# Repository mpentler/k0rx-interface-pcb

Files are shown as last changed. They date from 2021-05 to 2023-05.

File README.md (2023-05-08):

# k0rx-interface-pcb
A PCB implementation of an audio data mode interface designed by K0RX, David Andersen
Photo of PCB

Original circuit here: https://k0rx.com/blog/2017/11/baofeng.html

I made this up into a small 4x4cm PCB to replace a horrible stripboard prototype. I'm releasing the Gerber files and the KiCad project in case anyone wants to have a play. The project has now been upgraded to be compatible with KiCad V6, but some things may need reconnecting. Sorry. Same for V7.

There are more complex interfaces available to make or buy but I loved the simplicity of David's design. A small enclosure could be made for a box, and I've included an example of this in FreeCAD format also.

I had to change some resistors in my implementation as David mentions, and I totally missed out the potentiometer, opting for a single 2k2 resistor (edit 2023: my output is way hot - clearly needs the resistor value increasing). I also added a hard switch for toggling Tx/Rx as well as the optocoupler. I am only using a single audio channel as David does, so you can either leave the other one hanging or send to ground I guess. The Rx resistor may need some adjustment, see what level works for you (breadboard it and test, perhaps). I will change this to potentiometers for a V3 as different radios and PCs can vary wildly in level.

An improvement you may want to add is a proper connector for the radio cable rather than cutting the end off a cable and soldering it directly. Especially if mounting it in a box.

This interface works great for me for SSTV & APRS work and for general audio recording from the radio. The total cost of all of the parts (including PCB fabbing from JLCPCB) is around £15, the most expensive parts being the cables.

# Parts List

* R1 - High value for receive audio, typically 62k-100k Ohm
* R2 - 2.2k Ohm for transmit audio (this may need to be higher also, again, experimentation is useful)
* R3 - 330 Ohm
* C1 - 0.1uF ceramic capacitor
* T1 - 1:1 600 Ohm transformer
* U1 - PC817 Optocoupler to pull PTT to GND
* SW1 - SPDT slide switch for hard TX/RX switching
* J1 - TRRS jack socket
* J2 - Pin header or bare pads - Audio out, GND
* J3 - Pin header or bare pads - Audio in, PTT
* J4 - Pin header or bare pads - RS232

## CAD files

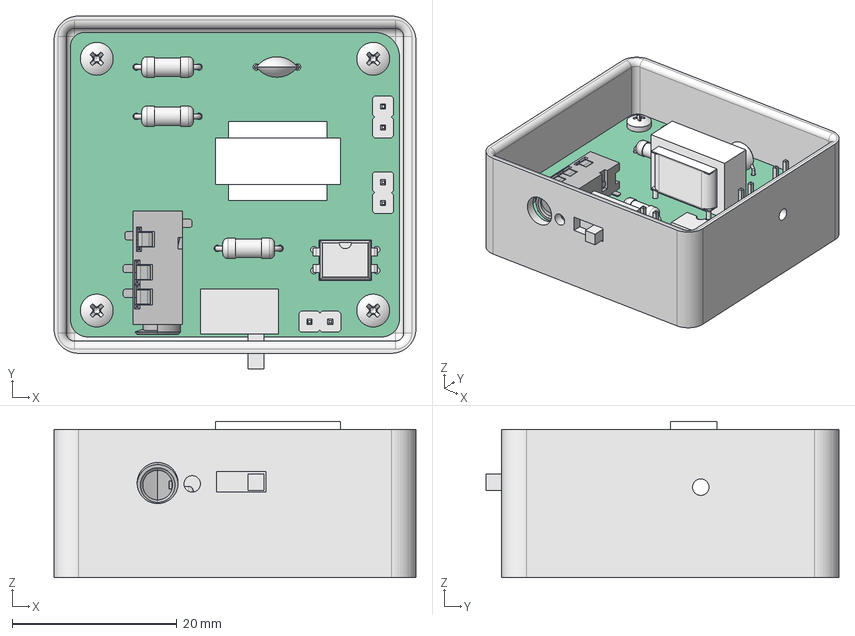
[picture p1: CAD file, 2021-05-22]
FreeCAD Box Design/Data Mode Radio Cable.FCStd
44.0 x 42.9 x 19.0 mm
M2x3-Screw
M2x3-Screw004
M2x3-Screw005
M2x3-Screw006
Pcb_8c7
J1_CUI_DEVICES_SJ2-3574A-SMT-TR_6004B39D
T1_Fusion003_60357E64
R3_R_Axial_DIN0207_L63mm_D25mm_P762mm_Horizontal_5FFD0C60 x 3
C1_C_Disc_D50mm_W25mm_P500mm_5FFD0E08
J2_PinHeader_1x02_P254mm_Vertical_5FFD0CA1 x 3
U1_DIP-4_W7.62mm_5FFD12AE
SW1_Fusion_6035CA9C

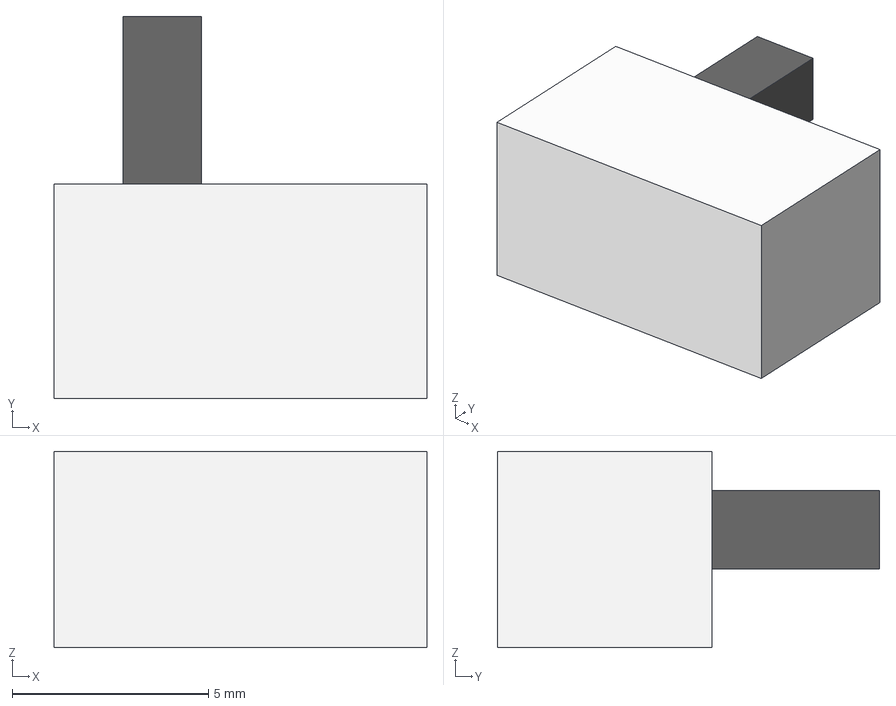
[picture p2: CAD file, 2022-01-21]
KiCad Project/3D Models/SPDT Switch.step
9.50 x 9.73 x 5.00 mm

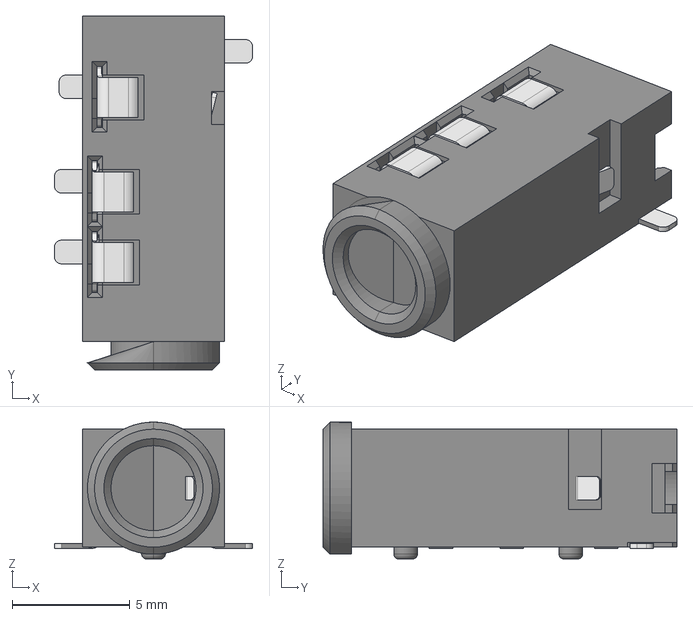
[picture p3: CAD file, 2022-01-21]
KiCad Project/3D Models/PJ-320A.step
8.40 x 15.0 x 5.80 mm

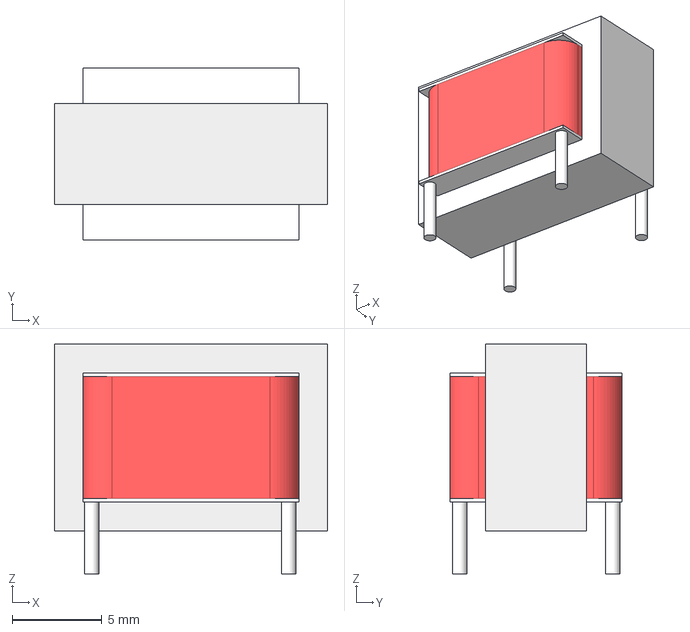
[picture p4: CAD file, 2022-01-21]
KiCad Project/3D Models/4 pin audio transformer.step
15.2 x 9.60 x 12.8 mm

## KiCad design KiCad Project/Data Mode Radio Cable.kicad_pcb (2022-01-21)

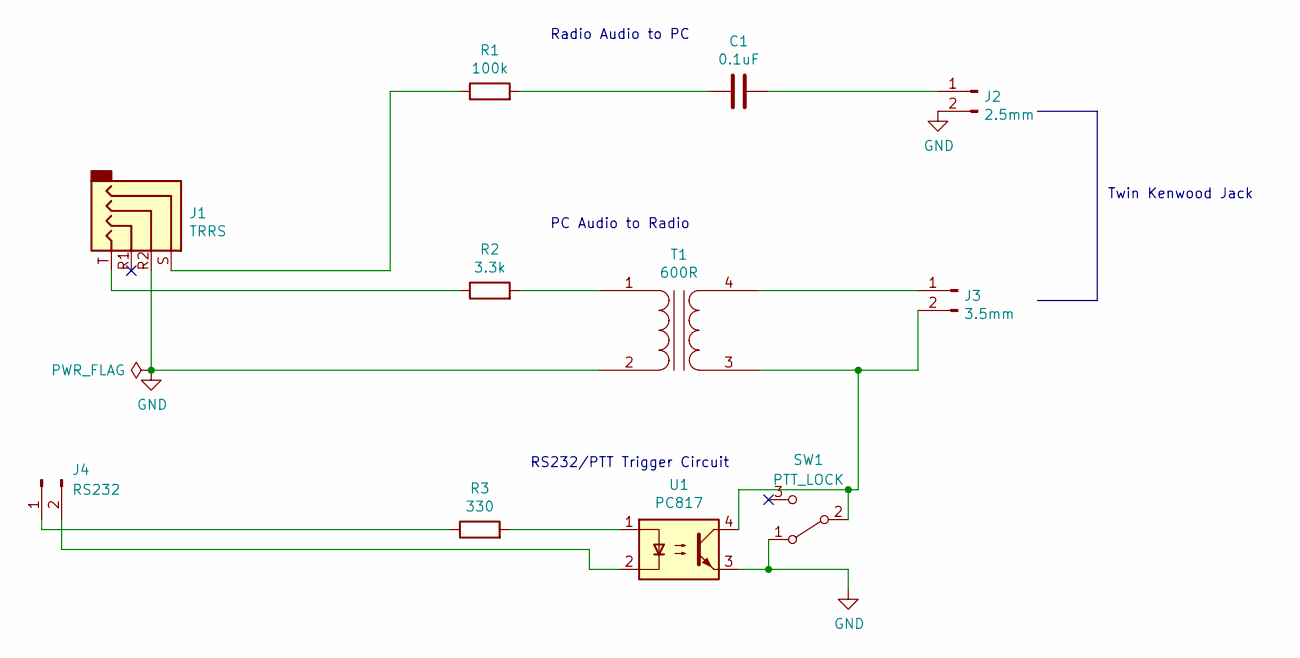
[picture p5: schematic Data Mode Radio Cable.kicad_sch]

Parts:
C1: 0.1uF; C_Disc_D5.0mm_W2.5mm_P5.00mm
J1: TRRS; TRRS-PJ-320A
J2: 2.5mm; PinHeader_1x02_P2.54mm_Vertical
J3: 3.5mm; PinHeader_1x02_P2.54mm_Vertical
J4: RS232; PinHeader_1x02_P2.54mm_Vertical
R1: 100k; R_Axial_DIN0207_L6.3mm_D2.5mm_P7.62mm_Horizontal
R2: 3.3k; R_Axial_DIN0207_L6.3mm_D2.5mm_P7.62mm_Horizontal
R3: 330; R_Axial_DIN0207_L6.3mm_D2.5mm_P7.62mm_Horizontal
SW1: PTT_LOCK; SPDT_Right_Angled_Switch
T1: 600R; 1-1_Audio_Transformer_600_ohm
U1: PC817; DIP-4_W7.62mm

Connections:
GND: J1.R2, J2.2, SW1.1 (A), T1.2 (AB), U1.3
unnamed: C1.1, R1.2
unnamed: C1.2, J2.1
unnamed: J1.S, R1.1
unnamed: J1.T, R2.1
unnamed: J3.1, T1.4 (SB)
unnamed: J3.2, SW1.2 (B), T1.3 (SA), U1.4
unnamed: J4.1, R3.1
unnamed: J4.2, U1.2
unnamed: R2.2, T1.1 (AA)
unnamed: R3.2, U1.1

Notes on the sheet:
RS232/PTT Trigger Circuit
Twin Kenwood Jack
PC Audio to Radio
Radio Audio to PC

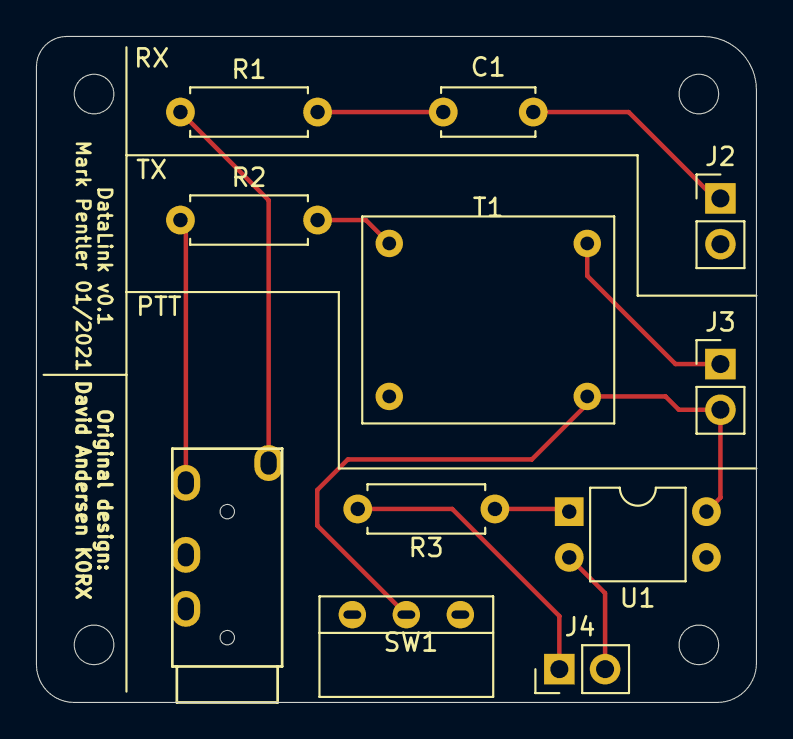
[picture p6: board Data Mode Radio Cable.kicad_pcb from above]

Board: 2 copper layers, 40.0 x 37.0 mm, 11 parts (0 on the bottom side), 11 nets.

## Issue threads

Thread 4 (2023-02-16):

Upgrade project to KiCad 7 and make sure everything is in order

mpentler, 2023-02-16:
After I get set up with KiCad 7 I will check that this all works ok and replace files as neccesary. Mostly I want to make sure that any included 3d models or footprints work fine when you load the project.

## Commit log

2021-05-22 Initial upload of project files
    Initial commit, I am quite stupid when it comes to KiCad so I don't quite know how to include the extra footprints and models I used yet...
    [Data Mode Radio Cable.FCStd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]
2021-05-22 Update README.md
    Added a photo of the board (if my markdown has worked...)
2022-01-21 Delete KiCad Project directory
    Preps for V6 files
    [Data Mode Radio Cable.kicad_pcb, Data Mode Radio Cable.sch]
2022-01-21 V6 file upgrade
    Replacing this folder with V6 files, hopefully all still works OK!
    [Data Mode Radio Cable.kicad_pcb, Data Mode Radio Cable.kicad_sch]
2022-01-21 3d model folder
    add custom models to project
    [4 pin audio transformer.step, PJ-320A.step, SPDT Switch.step]
2022-01-21 Custom footprint addition
    Copying library folder over now I know how to do them per-project
2022-01-21 Add files via upload
    Replaced project files with ones pointing to new per-project footprints
    [Data Mode Radio Cable.kicad_pcb, Data Mode Radio Cable.kicad_sch]
2022-01-21 Delete Data Mode Radio Cable.net
    Seems to be no longer needed in Kicad V6, all transparent between the apps
